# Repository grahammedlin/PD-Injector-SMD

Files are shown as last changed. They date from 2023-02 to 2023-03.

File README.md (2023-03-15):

**!!! Use at your own risk. 
May kill USB ports or worse. !!!**

Definitely don't connect two USB-C-to-A cables between your two favorite computers.

# PD-Injector 

Based on earlier versions by [Jana-Marie Hemsing](https://github.com/Jana-Marie/PD-Injector), [Clara Hobbs](https://git.clarahobbs.com/pd-buddy/pd-buddy-wye), and [tinyledmatrix](https://github.com/tinyledmatrix/PD-Injector-SMD).

This is a USB power delivery Power/Data injector. This version uses all USB-C receptacles. The data lines from one input and the power lines from the other are combined and present at the output. Therefore you can have a data connection from your (not PD capable) computer, while having power from a power supply. It only connects the USB2.0 data lines. Two receptacles means you will need to orient the power cables in the same direction.

Why? Earlier versions appear for Android Auto, where the head unit was insufficient to charge while running. The [Coolgear PD Injector](https://www.coolgear.com/product/usb-c-usb-b-power-delivery-adapter-wmounting-kit) is expensive. I'm using this to program devices while powered, e.g. the [PINECIL V2 soldering iron](https://wiki.pine64.org/wiki/Pinecil_Power_Supplies) and that [MHP30 tiny hotplate](https://www.adafruit.com/product/4948), and potentially run a 3D printer toolhead over USB instead of CAN+Power. These [HUSB328-based USB-C trigger boards](https://www.amazon.com/Coolgear-Delivery-Injector-Type-C-Device/dp/B075F6BD4Y/) are helpful for debugging. 

Interestingly, the Pinecil and MHP30 both use the Onsemi FUSB302MPX, but the Pinecil will not power if the second cable is an active cable like Thunderbolt, while the MHP30 will just fine.

<p float="left">
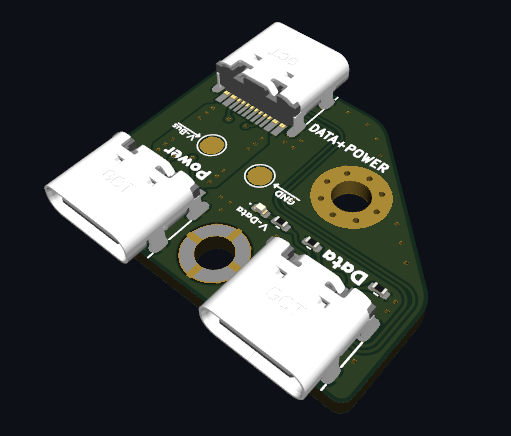
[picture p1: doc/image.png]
PD-Injector screenshot
  
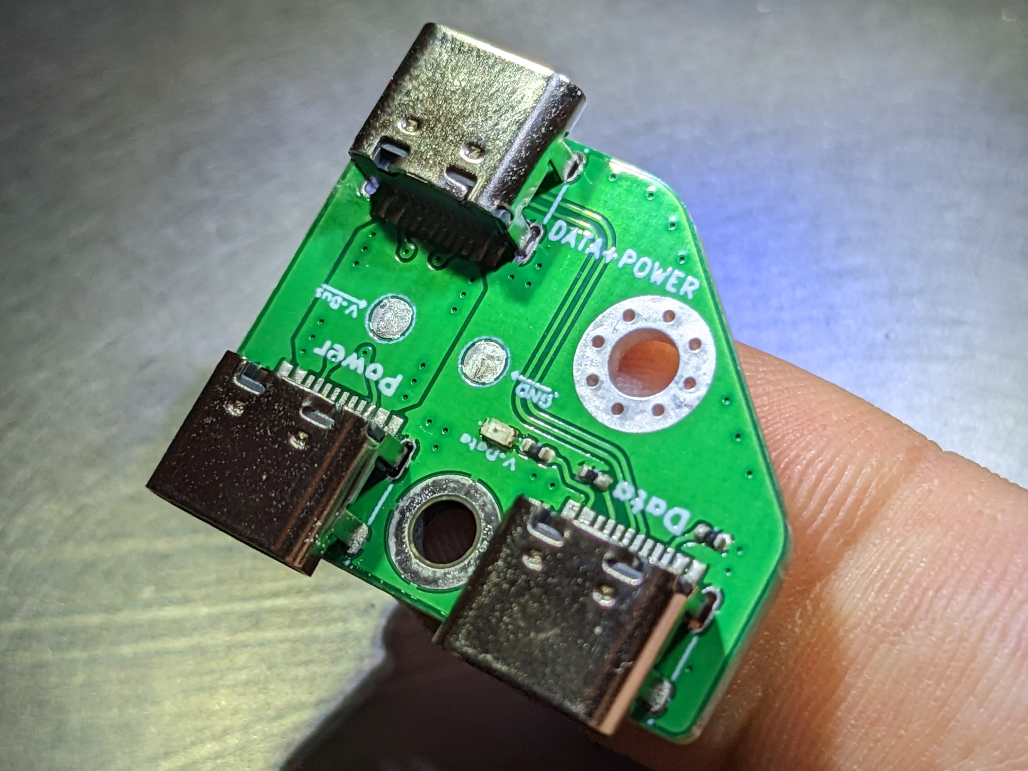
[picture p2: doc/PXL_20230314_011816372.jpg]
PD-Injector photo
  
</p>

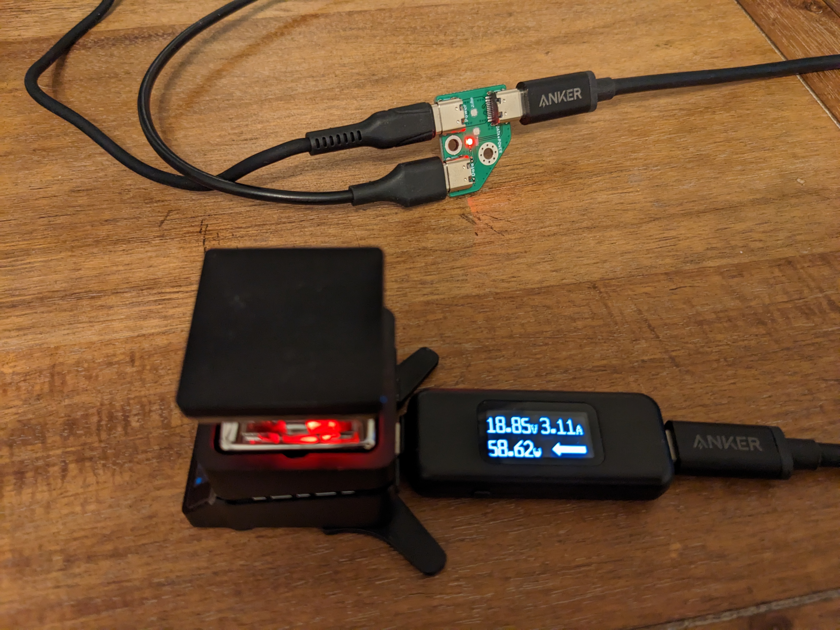
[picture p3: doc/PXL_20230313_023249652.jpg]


90 W power supply to read a USB-A thumb drive? Sure.

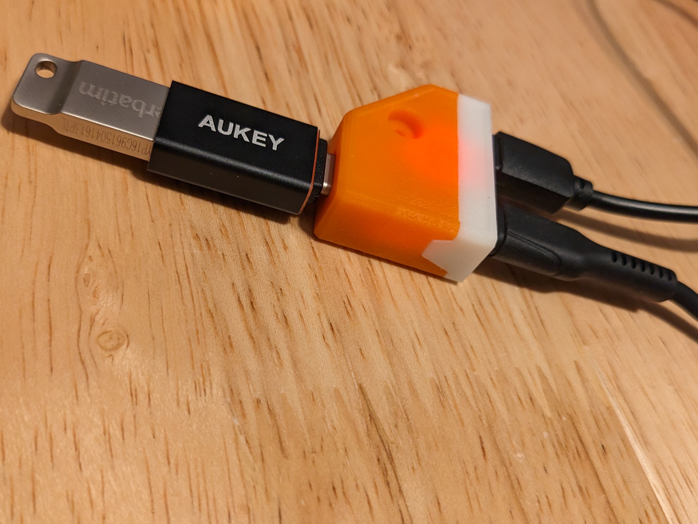
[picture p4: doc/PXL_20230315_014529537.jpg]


[//]: # (Connecting two devices with USB Type C receptacles with a USB Type C cable is the intended use. But if one receptacle isn't a device but a passive board, that's a problem.)
[//]: # (An E-Marker is required on all USB Type-C cables that support 5 amps and/or exceed 60 watts of power carrying capability)

# License
CERN Open Hardware Licence v1.2.  See LICENSE for more information.

## References
- [USB.org PD](https://www.usb.org/sites/default/files/D2T2-1%20-%20USB%20Power%20Delivery.pdf)
- [USB.org card edge gerbers](https://www.usb.org/document-library/usb-type-c-cable-assembly-signal-integrity-test-fixture-gerber-files)

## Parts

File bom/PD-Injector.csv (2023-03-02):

# | Reference | Qty | Value | Footprint | DNP
1 | D1 | 1 | LED | LED_SMD:LED_0402_1005Metric
2 | R1, R2, R3 | 3 | 5.1k | Resistor_SMD:R_0402_1005Metric
3 | USB-C1, USB-C2, USB-C3 | 3 | USB-C USB2.0 PD | PD-Injector:JAE_DX07S016JA1R1500

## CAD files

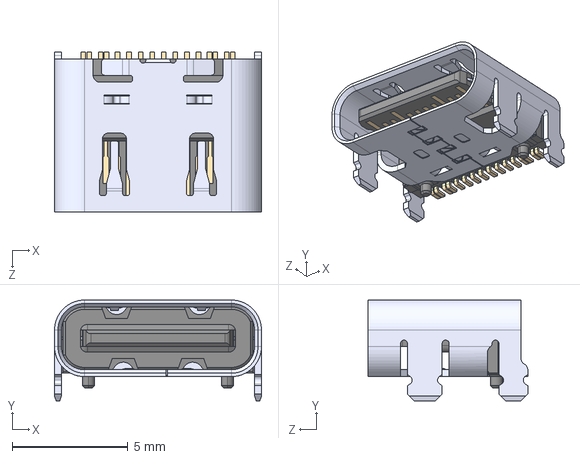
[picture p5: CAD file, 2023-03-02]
3D/JAE_DX07S016JA1R1500.STEP
8.94 x 4.36 x 6.90 mm

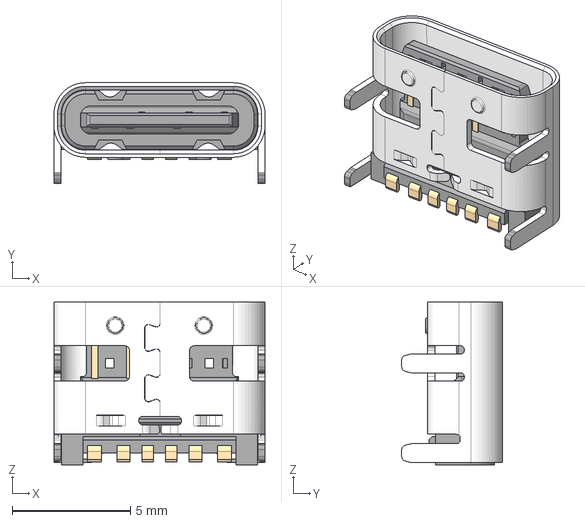
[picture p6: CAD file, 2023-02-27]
3D/USB4125-GF-A.stp
8.94 x 4.26 x 6.90 mm

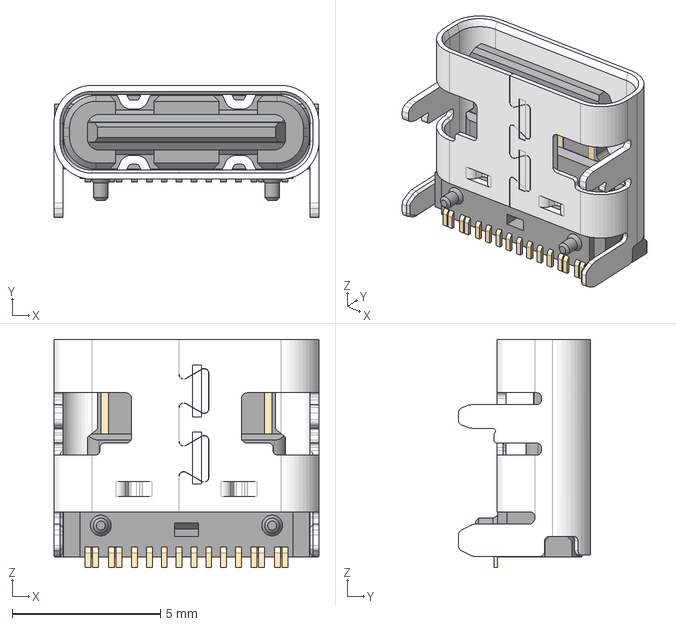
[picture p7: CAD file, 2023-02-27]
3D/USB4105-15-A-120.stp
8.94 x 4.46 x 7.70 mm
USB4105-15-A-120_PART2
USB4105-15-A-120_PART1

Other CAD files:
enclosure/PD-Injector-Enclosure.f3d

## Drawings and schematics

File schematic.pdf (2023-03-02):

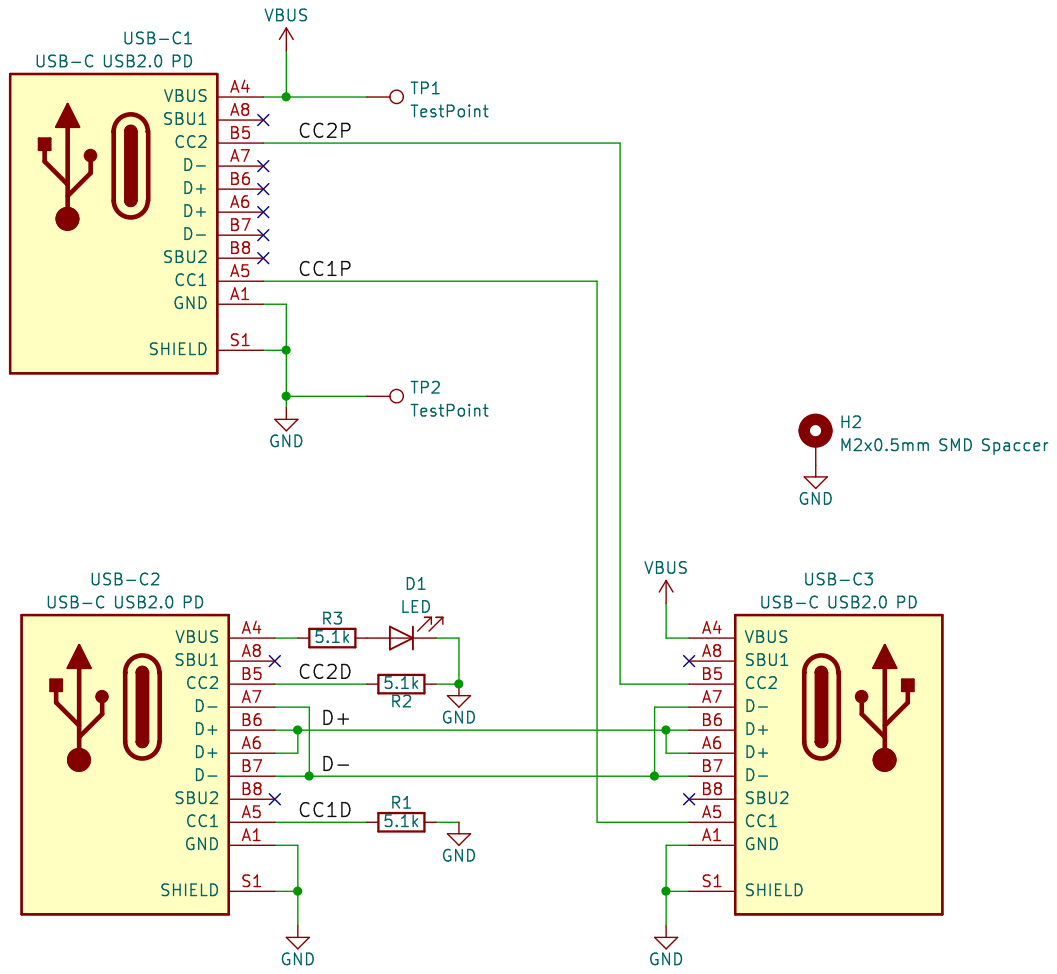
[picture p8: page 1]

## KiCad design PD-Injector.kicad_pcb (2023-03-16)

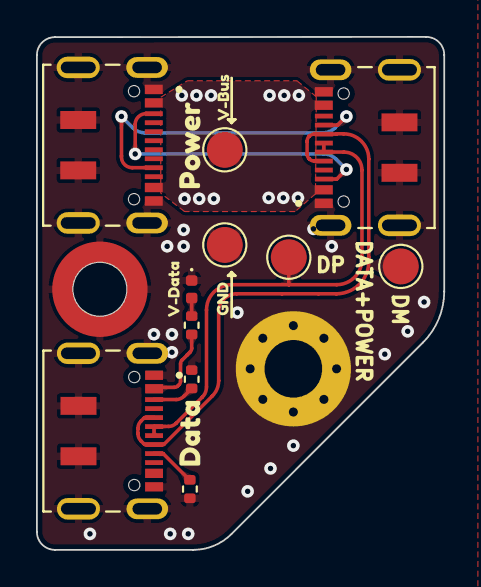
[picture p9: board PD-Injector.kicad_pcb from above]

Board: 2 copper layers, 22.6 x 28.5 mm, 18 parts (0 on the bottom side), 10 nets.

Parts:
D1: LED; LED_0402_1005Metric
H2: M2x0.5mm SMD Spaccer; WA-SMSI_9774005243
MK1: M3; MountingHole_3.2mm_M3_Pad_Via
R1, R2, R3: 5.1k; R_0402_1005Metric
TP1, TP2, TP2#2, TP2#3: TestPoint; TestPoint_Pad_D2.0mm
USB-C1, USB-C2, USB-C3: USB_C_Receptacle_USB2.0; JAE_DX07S016JA1R1500
kibuzzard-6334B7AE: G***; kibuzzard-6334B7AE
kibuzzard-6334B838: G***; kibuzzard-6334B838
kibuzzard-6334B904: G***; kibuzzard-6334B904
kibuzzard-63322175: G***; kibuzzard-63322175
kibuzzard-63322190: G***; kibuzzard-63322190

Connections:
/CC1D: R1.1, USB-C2.A5 (CC1)
/CC1P: USB-C1.A5 (CC1), USB-C3.A5 (CC1)
/CC2D: R2.2, USB-C2.B5 (CC2)
/CC2P: USB-C1.B5 (CC2), USB-C3.B5 (CC2)
/D+: TP2#3.1, USB-C2.A6 (D+), USB-C2.B6 (D+), USB-C3.A6 (D+), USB-C3.B6 (D+)
/D-: TP2#2.1, USB-C2.A7 (D-), USB-C2.B7 (D-), USB-C3.A7 (D-), USB-C3.B7 (D-)
GND: D1.1 (K), H2.1, MK1.1, R1.2, R2.1, TP2.1, USB-C1.A1 (GND), USB-C1.S1 (SHIELD), USB-C2.A1 (GND), USB-C2.S1 (SHIELD), USB-C3.A1 (GND), USB-C3.S1 (SHIELD)
unnamed: D1.2 (A), R3.2
unnamed: R3.1, USB-C2.A4 (VBUS)
VBUS: TP1.1, USB-C1.A4 (VBUS), USB-C3.A4 (VBUS)

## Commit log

2022-09-27 Initial cleanup and first push of edited Kicad/Readme
    [PD-Injector-B.Cu.gbl, PD-Injector-B.Mask.gbs, PD-Injector-B.Paste.gbp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]
2022-09-29 change of form factor and further ECAD work
    [PD-Injector-SMD.kicad_pcb, PD-Injector-SMD.kicad_sch, PD-Injector-SMD.step]
2022-10-12 finalized PCB work for V0.1
    [PD-Injector-SMD.kicad_pcb, PD-Injector-SMD.kicad_sch, outline.dxf]
2022-10-13 minor schematic clean up
    [PD-Injector-SMD.kicad_sch]
2023-02-24 updated kicad 7
    [PD-Injector-SMD.kicad_pcb, PD-Injector-SMD.kicad_sch]
2023-02-25 Swapped output to receptacle
    [PD-Injector-SMD.kicad_pcb, PD-Injector-SMD.kicad_sch]
2023-02-27 Update readme, minor mucking about
    [PD-Injector-SMD.kicad_pcb, PD-Injector-SMD.kicad_sch, USB4105-15-A-120.stp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]
2023-02-28 update pdf, cleanup
    [PD-Injector-SMD.step, PD-Injector.kicad_pcb, PD-Injector.kicad_sch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]
2023-03-02 switch USB-C part
    [JAE_DX07S016JA1R1500.STEP, PD-Injector.kicad_pcb, PD-Injector.kicad_sch]
2023-03-02 bom update
    [PD-Injector.csv]
2023-03-04 more vbus copper
    [PD-Injector.kicad_pcb, PD-Injector.kicad_sch]
2023-03-15 add enclosure
    [PD-Injector-Enclosure.f3d]
2023-03-16 add USB2.0 test pads
    [PD-Injector.kicad_pcb]

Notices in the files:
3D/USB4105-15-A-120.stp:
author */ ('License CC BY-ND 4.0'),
